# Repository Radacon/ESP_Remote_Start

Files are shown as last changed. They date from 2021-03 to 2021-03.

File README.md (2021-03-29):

# ESP_Remote_Start

<h2>Motivation & Abstract</h2>
<p> Chevy wanted $15/month to be able to start/lock/unlock/find my wife's new car with an app. This is silly but pretty useful. Is it worth $15/month? No, no it's not.</p>
<p> What I have done is developed a website that is hosted on an ESP8266. Through this website a user can start, stop, lock, and unlock their vehicle. The website is also capable of scheduling remote-start times. This is great in the winter when you don't think about starting your vehicle until you walk out. Snow in the forecast tonight? Schedule a remote start 10 minutes before you leave from work to help the scraping process. The extra idle-time is nice for getting the lubricant's moving again after sitting all night.</p>

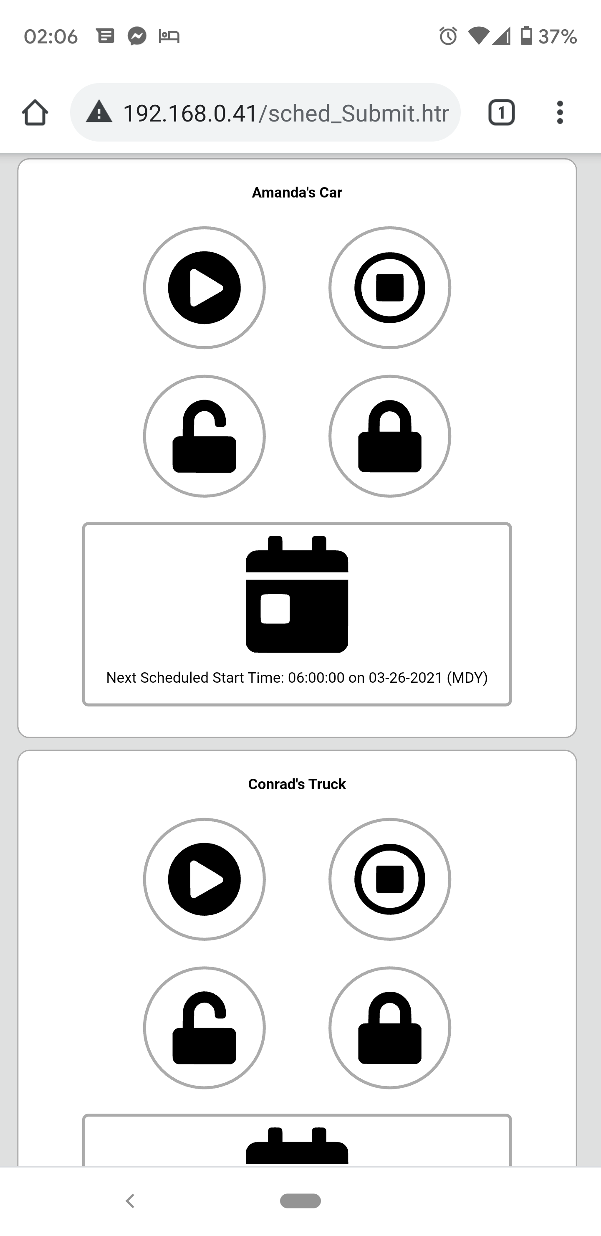
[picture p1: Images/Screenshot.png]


<h2>Warnings</h2>

<p> First thing's first: Please don't even consider building one of these if you park your cars in a garage. A single error in the code can kill, and the code is not without it's flaws! Second, I implement OTA updating, this is in no way locked down to prevent some rando with a laptop in your neighborhood from pushing nefarious code onto the device, unlocking your car, and stealing all of your stuff, all without walking into your house for the keys.</p> 
<p> With that said, if you park your vehicles outside, and are willing to accept the risk of someone remote starting it/unlocking it to steal your stuff then by all means continue on. </p>

<h2>Limitations</h2>
<p> I did a pretty good job making a minimum-viable-product (prototype) with the code. However there are several limitations. 
  
1) You can only use this service on a local network. You'll need to open it up to the internet to have access to stuff when you're away from your home. Please don't do this.
2) This only works while your vehicles are in range of the key-fob. 
3) I do a shoddy job converting from Month-day-year-hour-minute-second to Epoch time. It works, but, I'm not quite sure how. 
4) Currently this code only supports up to 2 vehicles, Amanda's (AF) and Conrad's (CF). The hardware on the Wemos could support up to 3 vehicles. 

<h2>How to use this</h2>

1) Get a Wemos ESP8266 unit. 
2) Upload the entire sketchbook onto the unit (after entering in your SSID/Password). 
3) Download the ESP8266 Sketch Data Upload tool
4) Upload the HTML, CSS, Icons, etc from the Data folder onto your ESP8266. 
5) Connect to http://cars.local to access the website. 
6) Reverse engineer your key-fobs. 
7) ????
8) Profit.

<h2>Reverse Engineering</h2>
<p>This is pretty easy, 3.3V (from your ESP) connects to + on the fob and Gnd connects to -. Okay now what about the buttons? With my sample size of two, the microcontroller embedded in the key fobs uses a pull-up topology. Follow the traces on the fob to determine which ones are connected to the microcontroller and which ones are ground connections. From here, you can solder wires from the ESP GPIO pins to the pads feeding into the microcontroller.</p>

<h3>Disclaimer</h3>
<p> This project is a proof of concept. It is by no means a finished product and should not be treated as such. This is here to help you help me get my foot in the door with HTML/CSS/AJAX and interfacing an ESP8266 with a real-world device. Please use common sense. This is not code that you should trust for your safety.</p>

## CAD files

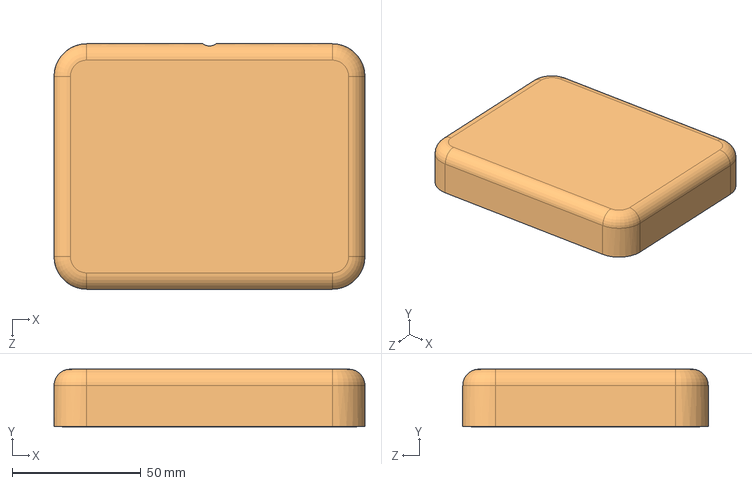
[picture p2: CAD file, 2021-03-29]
3D_Files/Assem1.SLDASM
120.7 x 22.4 x 95.2 mm
Base
Lid

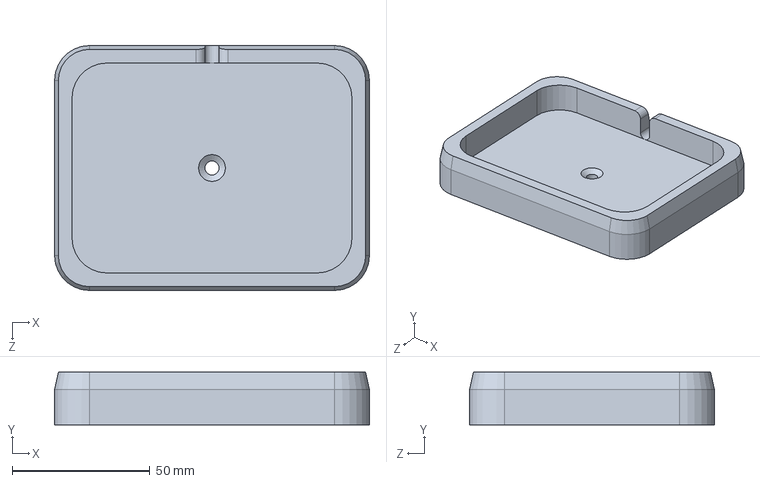
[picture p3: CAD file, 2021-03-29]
3D_Files/Base.SLDPRT
114.3 x 19.0 x 88.9 mm

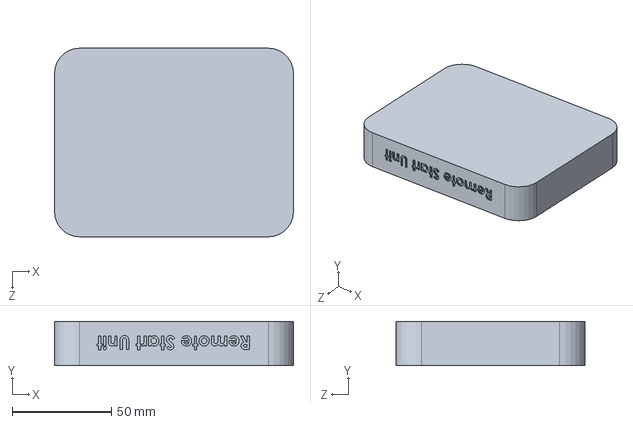
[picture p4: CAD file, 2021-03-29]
3D_Files/Lid.SLDPRT
120.7 x 22.2 x 95.2 mm

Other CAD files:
3D_Files/Base.STL
3D_Files/Lid.STL

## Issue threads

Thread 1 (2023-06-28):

Did you have to make any adjustments to the fobs?

mattdsteele, 2023-06-28:
Hi, this is a cool project! I'm interested in something similar, but am trying to figure out how I'd wire it up and thought you might have advice.

I've got a similar fob, but I can't seem to trace any of the buttons to pads I could easily wire up to an 8266. Running a multimeter, I can see 3.3V flowing between the button pads normally, which drops down to 0V when I push the button down.

At this point, I'm thinking the simplest way for me to hook this up would be to desolder the button from the board, and set up a `digitalWrite()` against a wire running directly to the pad. Did you have to do anything similar?

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

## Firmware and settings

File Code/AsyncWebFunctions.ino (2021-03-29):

void handleNotFound() {
  String message = "File Not Found\n\n";
  message += "URI: ";
  message += server.uri();
  message += "\nMethod: ";
  message += (server.method() == HTTP_GET) ? "GET" : "POST";
  message += "\nArguments: ";
  message += server.args();
  message += "\n";
 
  for (uint8_t i = 0; i < server.args(); i++) {
    message += " " + server.argName(i) + ": " + server.arg(i) + "\n";
  }
 
  server.send(404, "text/plain", message);
}
 
bool loadFromSPIFFS(String path) {
  
  String dataType = "text/html";

  if(path.endsWith(".html")) dataType = "text/html";
  else if(path.endsWith(".htm")) dataType = "text/html";
  else if(path.endsWith(".svg")) dataType = "image/svg+xml";
  else if(path.endsWith(".css")) dataType = "text/css";
  else if(path.endsWith(".js")) dataType = "application/javascript";
  else if(path.endsWith(".png")) dataType = "image/png";
  else if(path.endsWith(".gif")) dataType = "image/gif";
  else if(path.endsWith(".jpg")) dataType = "image/jpeg";
  else if(path.endsWith(".ico")) dataType = "image/x-icon";
  else if(path.endsWith(".xml")) dataType = "text/xml";
  else if(path.endsWith(".pdf")) dataType = "application/pdf";
  else if(path.endsWith(".zip")) dataType = "application/zip";
  
  File dataFile = SPIFFS.open(path.c_str(), "r");
  
  if (server.hasArg("download")) dataType = "application/octet-stream";
  if (server.streamFile(dataFile, dataType) != dataFile.size()) {
  }
 
  Serial.print("Requested page -> ");
  Serial.println(path);
  if (SPIFFS.exists(path)){
      File dataFile = SPIFFS.open(path, "r");
      if (!dataFile) {
          handleNotFound();
          return false;
      }
 
      if (server.streamFile(dataFile, dataType) != dataFile.size()) {
        Serial.println("Sent less data than expected!");
      }else{
          Serial.println("Page served!");
      }
 
      dataFile.close();
  }else{
      handleNotFound();
      return false;
  }
  return true;
}

void printDirectory(File dir, int numTabs) {
  while (true) {
 
    File entry =  dir.openNextFile();
    if (! entry) {
      // no more files
      break;
    }
    for (uint8_t i = 0; i < numTabs; i++) {
      Serial.print('\t');
    }
    Serial.print(entry.name());
    if (entry.isDirectory()) {
      Serial.println("/");
      printDirectory(entry, numTabs + 1);
    } else {
      // files have sizes, directories do not
      Serial.print("\t\t");
      Serial.println(entry.size(), DEC);
    }
    entry.close();
  }
} 
 
void handleRoot(void) {
    loadFromSPIFFS("/index.html");
}


void schedule_Autostart(void){
    String Temp;
    String SplashMSG = "";
    String hstr, mstr, sstr, ystr, mostr, dstr;
    int h,m,s,y,mo,d;
    long epoch_alarm;
    //Yes I had to do this. Apparently arg(0) is ambiguious. 
    int zero = 0;
    //Each POST request (for scheduling) comes with 3 arguments
    if(server.args()==3){
      //Process Amanda or Conrad's times in the same logic bracket.
      if(server.argName(0)=="AmandaDateStart" || server.argName(0)=="ConradDateStart"){
        Temp = server.arg(1);
        h=Temp.substring(0,2).toInt();
        hstr=Temp.substring(0,2);
        
        m=Temp.substring(3,5).toInt();
        mstr=Temp.substring(3,5);
        s=0;
        sstr="00";
        
        Temp = server.arg(zero);
        
        y=Temp.substring(0,4).toInt();
        ystr=Temp.substring(0,4);
        
        mo=Temp.substring(5,7).toInt();
        mostr=Temp.substring(5,7);
        
        d=Temp.substring(8,10).toInt();
        dstr=Temp.substring(8,10);

        epoch_alarm = convert_to_epoch(d, mo, y, h, m, s);
        SplashMSG = SplashMSG + hstr + ":" + mstr + ":" + sstr + " on " + mostr + "-" + dstr + "-" + ystr;
      }
    }
    //If this request had argument name Amanda, schedule her alarm
    if(server.argName(0)=="AmandaDateStart")
    {
      //Since TimeAlarms does not Support day/month/year for alarm variables
      //We'll use the timer function where we can specify when to execute
      //an action in terms of number of seconds from now.

      //Sanity check to make sure we're at least at 3/24/21 (Day of Creation of this code)
      if(timeClient.getEpochTime()>1616602966)
      {
        AmandaSchedDate = epoch_alarm;
        AmandaSchedDateStr = SplashMSG;
        Serial.println("Amanda is scheduled for " + SplashMSG);
      }
      
    }

    //If this request had argument name Conrad, schedule his alarm
    if(server.argName(0)=="ConradDateStart")
    {
      if(timeClient.getEpochTime()>1616602966)
      {
        ConradSchedDate = epoch_alarm;
        ConradSchedDateStr = SplashMSG;
        Serial.println("Conrad is scheduled for " + SplashMSG);
      }
    }
    //In the future write This Time (epoch and readable) to SPI Flash.
    //Re-instantiate the alarms whenever a reboot happens/power outage. 
    //For now we'll store these as strings in RAM
    handleRoot();
    //server.send(200, "text/plain", ("Autostart scheduled for: "+SplashMSG));
    //Kick the user back to the mainpage after scheduling    
    //loadFromSPIFFS("/index.html");
}

void reboot_esp(void)
{
  loadFromSPIFFS("/reboot.html");
  //Can't use a delay since we need to pop back into the main loop 
  //to serve .css and .svg elements of the reboot page.
  //So we'll schedule a reboot for 5 seconds from now.
  ESP_Reset_Date = timeClient.getEpochTime()+5;
  Serial.println("Rebooting ESP32 (command sent via web interface)");
}
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

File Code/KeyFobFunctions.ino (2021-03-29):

//Amanda's KeyFob
int Amanda_Lock_GPIO = 13; //Green
int Amanda_Unlock_GPIO = 12; //Blue/White
int Amanda_Start_GPIO = 15; //Blue

//Conrad's KeyFob
//Pinouts courtesy of https://randomnerdtutorials.com/esp8266-pinout-reference-gpios/
//Blue
int Conrad_Lock_GPIO = 2;
//Blue/White
int Conrad_Unlock_GPIO = 14;
//Green Wire
int Conrad_Start_GPIO = 0;

//Lots of delays required to emulate button presses
const int button_delay = 400;
const int button_off_delay = 250;
const int start_hold = 4000;

void init_GPIO()
{
  //Initialize the GPIO Pins for Output Only and set to low
  //Amanda
  pinMode(Amanda_Lock_GPIO, OUTPUT);
  digitalWrite(Amanda_Lock_GPIO,HIGH);
  pinMode(Amanda_Unlock_GPIO, OUTPUT);
  digitalWrite(Amanda_Unlock_GPIO,HIGH);
  pinMode(Amanda_Start_GPIO, OUTPUT);
  digitalWrite(Amanda_Start_GPIO,HIGH);
  //Conrad
  pinMode(Conrad_Lock_GPIO, OUTPUT);
  digitalWrite(Conrad_Lock_GPIO, HIGH);
  pinMode(Conrad_Unlock_GPIO, OUTPUT);
  digitalWrite(Conrad_Unlock_GPIO, HIGH);
  pinMode(Conrad_Start_GPIO, OUTPUT);
  digitalWrite(Conrad_Start_GPIO, HIGH);
}

void startAmanda()
{
  Serial.println("Starting Amanda's Car");
  //Press Lock Twice
  lockAmanda();
  //Press and Hold Start for 3 Seconds
  digitalWrite(Amanda_Start_GPIO, LOW);
  delay(start_hold);
  digitalWrite(Amanda_Start_GPIO, HIGH);
  //Serial.println("Amanda's Car Started");
  server.send(200, "text/plain", "ok");
  //Handle-restarts with a seperate scheduler
  //15 minute timeout on the vehicle
}

void stopAmanda()
{
  //Serial.println("Stopping Amanda's Car");
  digitalWrite(Amanda_Start_GPIO, LOW);
  delay(start_hold);
  digitalWrite(Amanda_Start_GPIO, HIGH);
  server.send(200);
}

void lockAmanda(){
  //Serial.println("Locking Amanda's Car");
  //Press Lock Twice to get audio feedback
  digitalWrite(Amanda_Lock_GPIO, LOW);
  delay(button_delay);
  digitalWrite(Amanda_Lock_GPIO, HIGH);
  delay(button_off_delay);
  digitalWrite(Amanda_Lock_GPIO, LOW);
  delay(button_delay);
  digitalWrite(Amanda_Lock_GPIO, HIGH);
  delay(button_off_delay);
  digitalWrite(Amanda_Lock_GPIO, LOW);
  delay(button_delay);
  digitalWrite(Amanda_Lock_GPIO, HIGH);
  delay(button_off_delay);
  server.send(200);
}

void unlockAmanda(){
  //Serial.println("Unlocking Amanda's Car");
  //Press unlock Twice to unlock all doors
  digitalWrite(Amanda_Unlock_GPIO, LOW);
  delay(button_delay);
  digitalWrite(Amanda_Unlock_GPIO, HIGH);
  delay(button_off_delay);
  digitalWrite(Amanda_Unlock_GPIO, LOW);
  delay(button_delay);
  digitalWrite(Amanda_Unlock_GPIO, HIGH);
  delay(button_off_delay);
   digitalWrite(Amanda_Unlock_GPIO, LOW);
  delay(button_delay);
  digitalWrite(Amanda_Unlock_GPIO, HIGH);
  delay(button_off_delay);
  server.send(200);
}

void startConrad(){
  //Serial.println("Starting Conrad's Truck");
  //Press Lock Twice
  lockConrad();
  //Press and Hold Start for 3 Seconds
  digitalWrite(Conrad_Start_GPIO, LOW);
  delay(start_hold);
  digitalWrite(Conrad_Start_GPIO, HIGH);
  server.send(200);
  //Handle-restarts with a seperate scheduler
  //15 minute timeout on the vehicle
}

void stopConrad()
{
  //Serial.println("Stopping Conrad's Truck");
  digitalWrite(Conrad_Start_GPIO, LOW);
  delay(start_hold);
  digitalWrite(Conrad_Start_GPIO, HIGH);
  server.send(200);
}

void lockConrad(){
  //Serial.println("Locking Conrad's Truck");
  //Press Lock Twice to get audio feedback
  digitalWrite(Conrad_Lock_GPIO, LOW);
  delay(button_delay);
  digitalWrite(Conrad_Lock_GPIO, HIGH);
  delay(button_off_delay);
  digitalWrite(Conrad_Lock_GPIO, LOW);
  delay(button_delay);
  digitalWrite(Conrad_Lock_GPIO, HIGH);
  delay(button_off_delay);
  digitalWrite(Conrad_Lock_GPIO, LOW);
  delay(button_delay);
  digitalWrite(Conrad_Lock_GPIO, HIGH);
  delay(button_off_delay);
  server.send(200);
}

void unlockConrad(){
  //Serial.println("Unlocking Conrad's Truck");
  //Press Lock Twice to get audio feedback
  digitalWrite(Conrad_Unlock_GPIO, LOW);
  delay(button_delay);
  digitalWrite(Conrad_Unlock_GPIO, HIGH);
  delay(button_off_delay);
  digitalWrite(Conrad_Unlock_GPIO, LOW);
  delay(button_delay);
  digitalWrite(Conrad_Unlock_GPIO, HIGH);
  delay(button_off_delay);
  digitalWrite(Conrad_Unlock_GPIO, LOW);
  delay(button_delay);
  digitalWrite(Conrad_Unlock_GPIO, HIGH);
  delay(button_off_delay);
  server.send(200);
}
